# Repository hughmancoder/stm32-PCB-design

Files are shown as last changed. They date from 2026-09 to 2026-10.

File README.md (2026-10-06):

# stm32-PCB-design

PCB board for `STM32F103C8T6` Microcontroller, a micro usb power supply, a regulator to power the mcu to 3.3V, and a crystal oscillator for the mcu. It has a reset switch to boot the board, a UART interface UART (Universal Asynchronous Receiver-Transmitter) to  uses two wires to exchange serial data between devices without a shared clock, as well as Serial Wire Debug (SWD) which is a  hardware interface designed by ARM for programming and debugging ARM-based microcontrollers using a st-link programmer. 

## Schematic
**Microcontroller and USB**

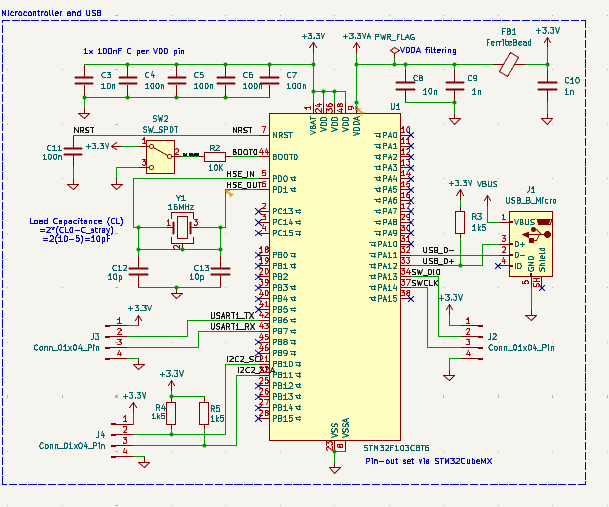
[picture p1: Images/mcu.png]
MCU


**Power Supply**

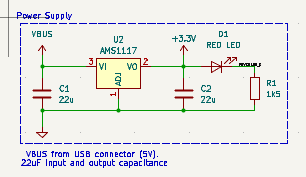
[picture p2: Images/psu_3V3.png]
Power Supply


## Board

**3D view**
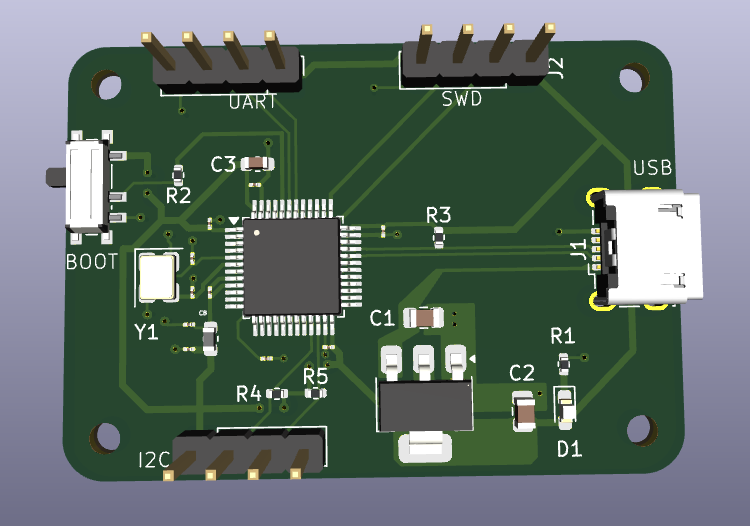
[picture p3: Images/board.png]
Board


**layout**
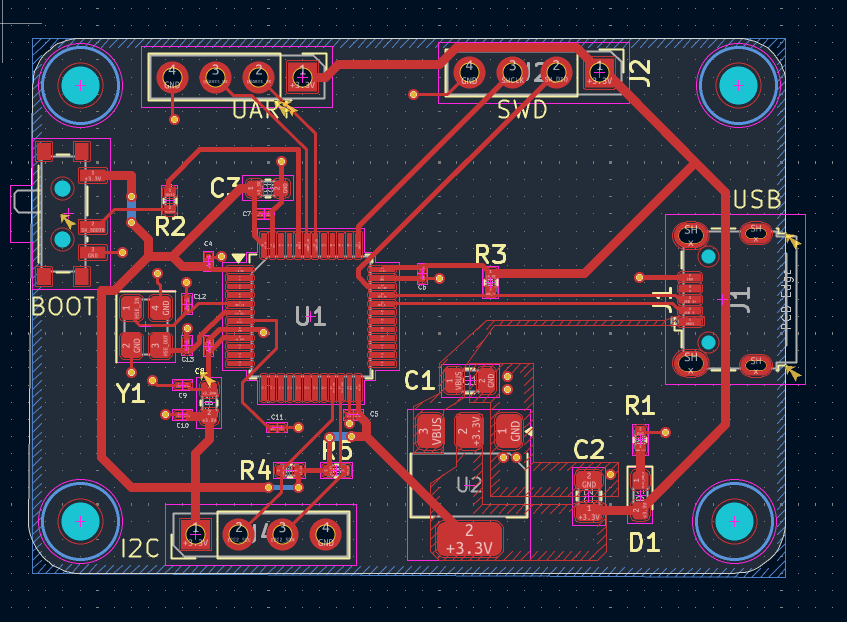
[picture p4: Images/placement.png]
Layout


## Manufacturing

Manufacturing gerber files, drill files, and Bill of Materials (BOM) are located in the `Manufacturing` folder.

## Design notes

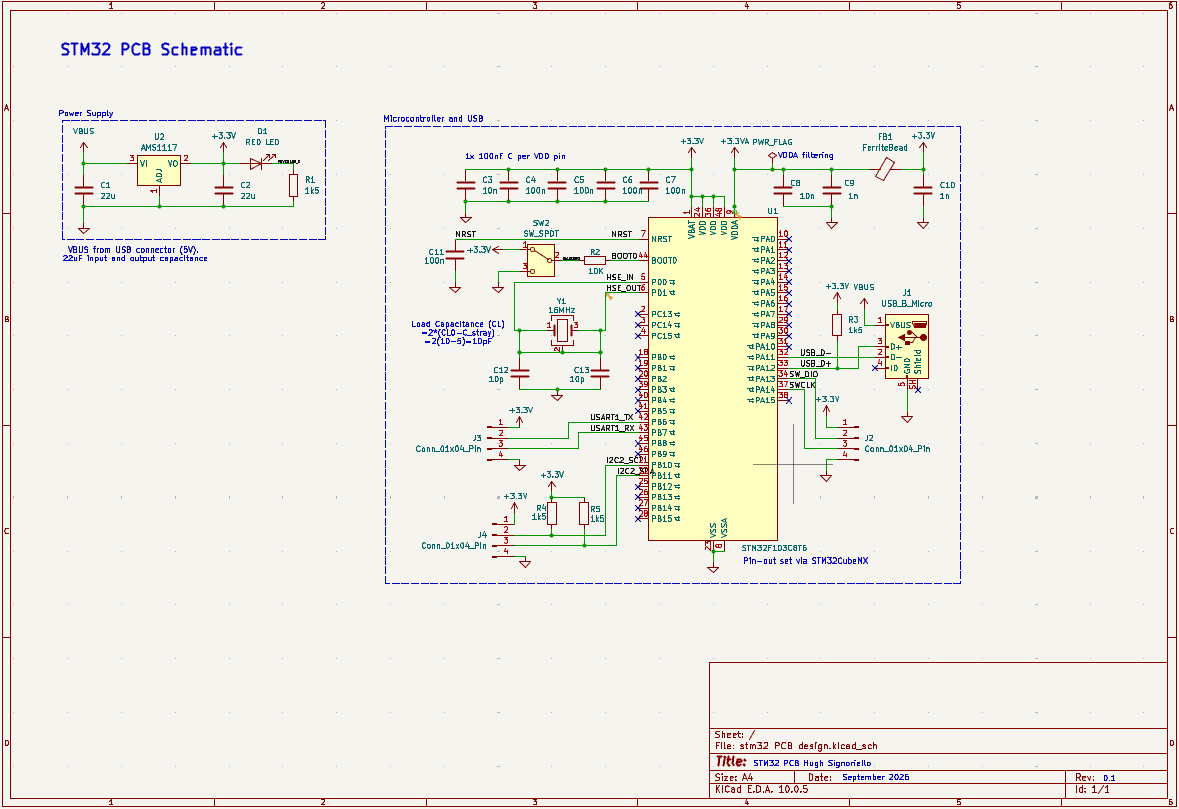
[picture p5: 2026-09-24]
Images/schematic_2026_09_24.png

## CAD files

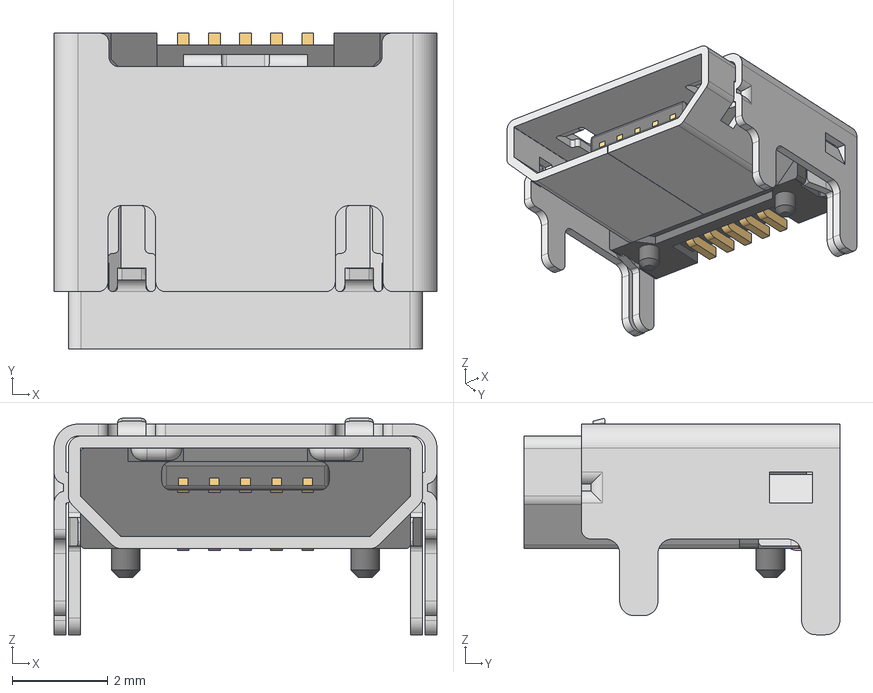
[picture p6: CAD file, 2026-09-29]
629105150521 (rev1).stp
8.00 x 6.60 x 4.52 mm
629105150521_Housing
629105150521_Pin1 x 4
629105150521_Pin2
629105150521_Shielding2
629105150521_Shielding

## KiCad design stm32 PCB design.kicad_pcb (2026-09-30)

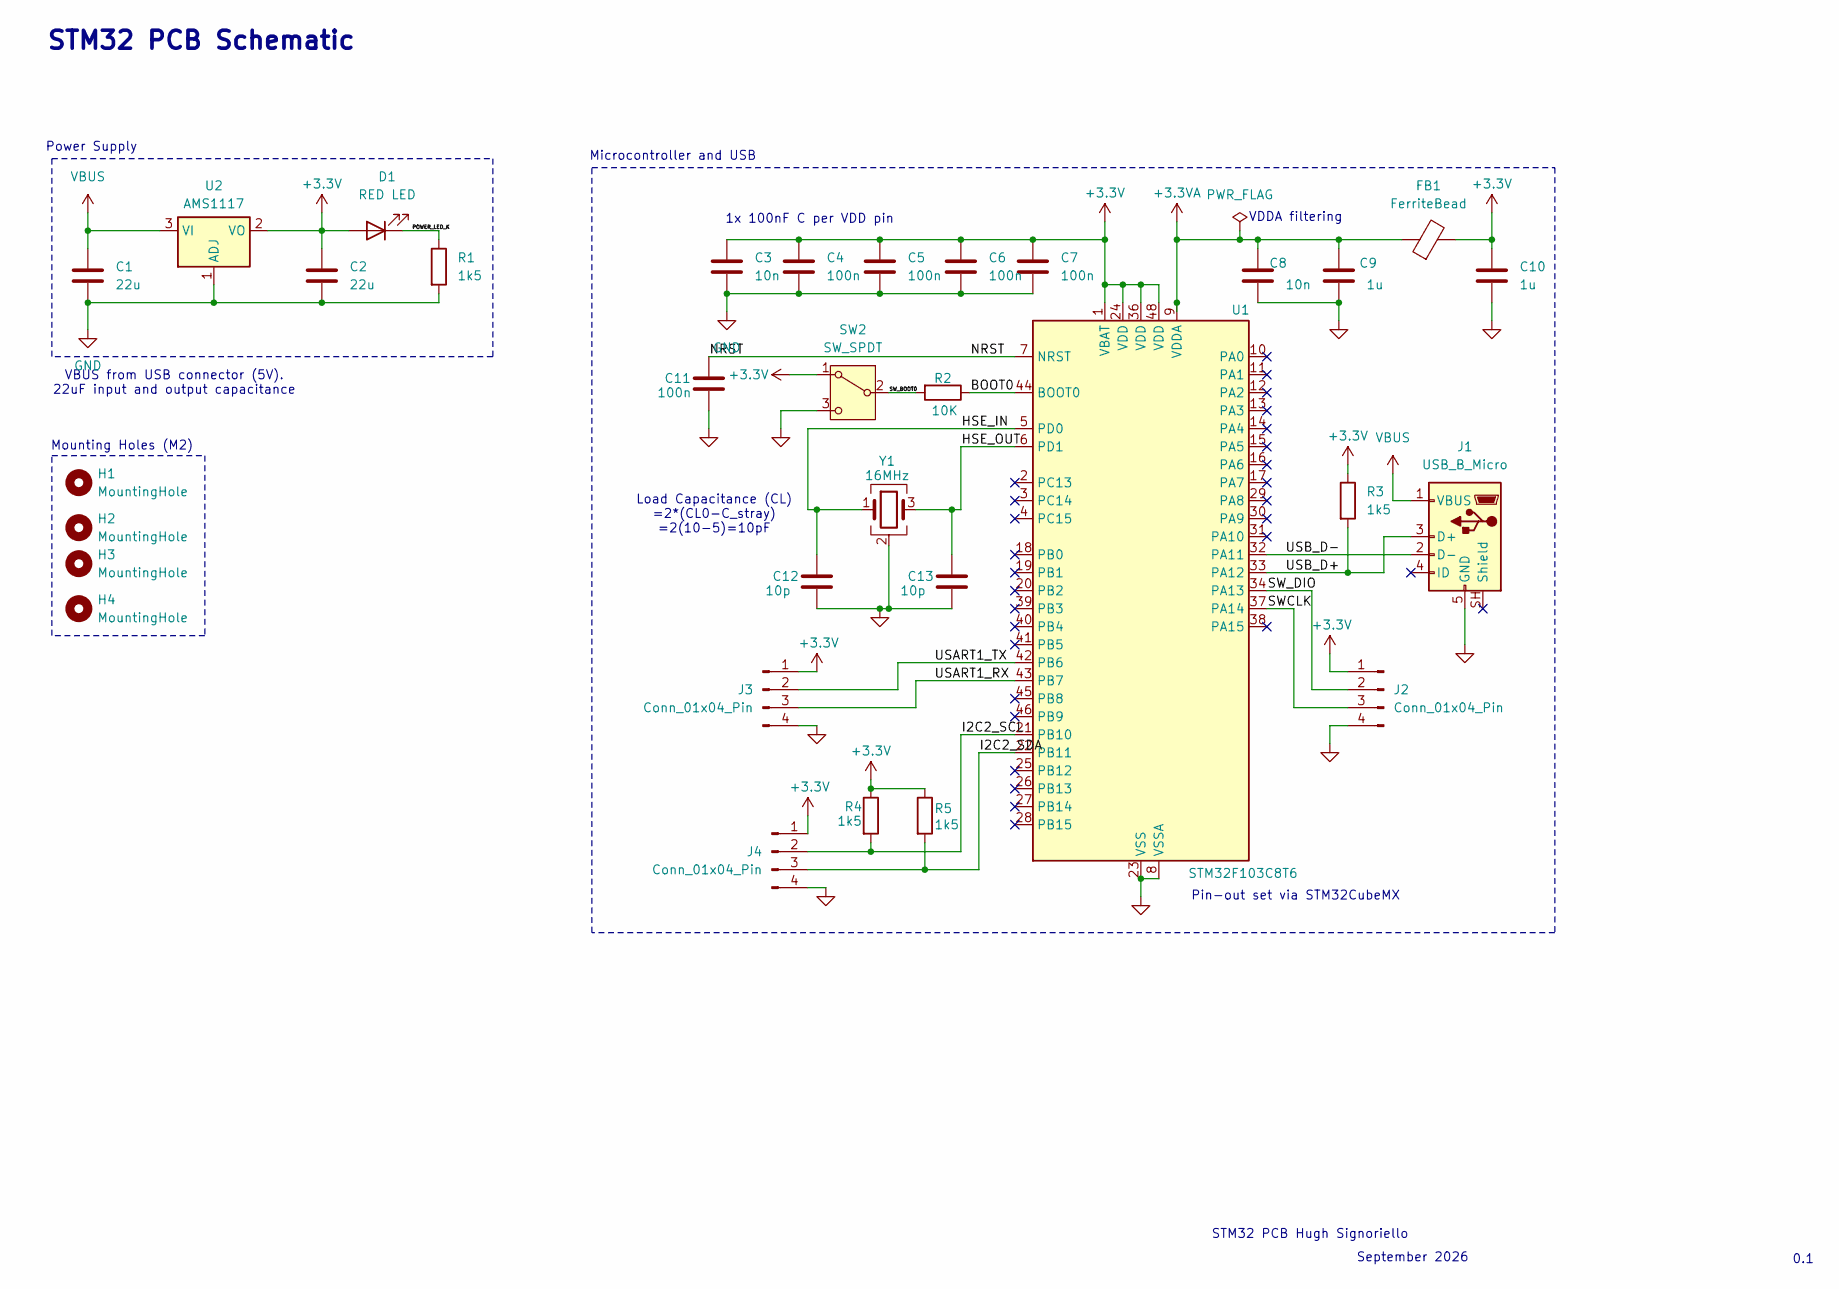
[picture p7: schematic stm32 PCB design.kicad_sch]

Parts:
C1, C2: 22u; C_0805_2012Metric
C3: 10n; C_0603_1608Metric
C4, C5, C6, C7, C11: 100n; C_01005_0402Metric
C8: 10n; C_01005_0402Metric
C9, C10: 1u; C_01005_0402Metric
C12, C13: 10p; C_01005_0402Metric
D1: RED LED; LED_0603_1608Metric_Pad1.05x0.95mm_HandSolder
FB1: FerriteBead; L_0603_1608Metric
H1, H2, H3, H4: MountingHole; MountingHole_2.2mm_M2
J1: USB_B_Micro; USB_Micro-B_Wuerth_629105150521
J2, J3, J4: Conn_01x04_Pin; PinHeader_1x04_P2.54mm_Vertical
R1, R3, R4, R5: 1k5; R_0402_1005Metric
R2: 10K; R_0402_1005Metric
SW2: SW_SPDT; SW_SPDT_PCM12
U1: STM32F103C8T6; LQFP-48_7x7mm_P0.5mm
U2: AMS1117; SOT-223-3_TabPin2
Y1: 16MHz; Crystal_SMD_3225-4Pin_3.2x2.5mm

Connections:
+3.3V: C2.1, C3.1, C4.1, C5.1, C6.1, C7.1, C10.1, D1.2 (A), FB1.2, J2.1, J3.1, J4.1, R3.1, R4.1, R5.1, SW2.1 (A), U1.1 (VBAT), U1.24 (VDD), U1.36 (VDD), U1.48 (VDD), U2.2 (VO)
+3.3VA: C8.1, C9.1, FB1.1, U1.9 (VDDA)
/BOOT0: R2.1, U1.44 (BOOT0)
/HSE_IN: C12.1, U1.5 (PD0), Y1.1
/HSE_OUT: C13.1, U1.6 (PD1), Y1.3
/I2C2_SCL: J4.2, R4.2, U1.21 (PB10)
/I2C2_SDA: J4.3, R5.2, U1.22 (PB11)
/NRST: C11.1, U1.7 (NRST)
/POWER_LED_K: D1.1 (K), R1.1
/SWCLK: J2.3, U1.37 (PA14)
/SW_BOOT0: R2.2, SW2.2 (B)
/SW_DIO: J2.2, U1.34 (PA13)
/USART1_RX: J3.3, U1.43 (PB7)
/USART1_TX: J3.2, U1.42 (PB6)
/USB_D+: J1.3 (D+), R3.2, U1.33 (PA12)
/USB_D-: J1.2 (D-), U1.32 (PA11)
GND: C1.2, C2.2, C3.2, C4.2, C5.2, C6.2, C7.2, C8.2, C9.2, C10.2, C11.2, C12.2, C13.2, J1.5 (GND), J2.4, J3.4, J4.4, R1.2, SW2.3 (C), U1.8 (VSSA), U1.23 (VSS), U1.35 (VSS), U1.47 (VSS), U2.1 (ADJ), Y1.2 (G), Y1.4 (G)
VBUS: C1.1, J1.1 (VBUS), U2.3 (VI)

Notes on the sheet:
VDDA filtering
VBUS from USB connector (5V). 22uF input and output capacitance
Power Supply
Microcontroller and USB
1x 100nF C per VDD pin
Pin-out set via STM32CubeMX
0.1
September 2026
STM32 PCB Hugh Signoriello
Load Capacitance (CL) =2*(CL0-C_stray) =2(10-5)=10pF
Mounting Holes (M2)
STM32 PCB Schematic

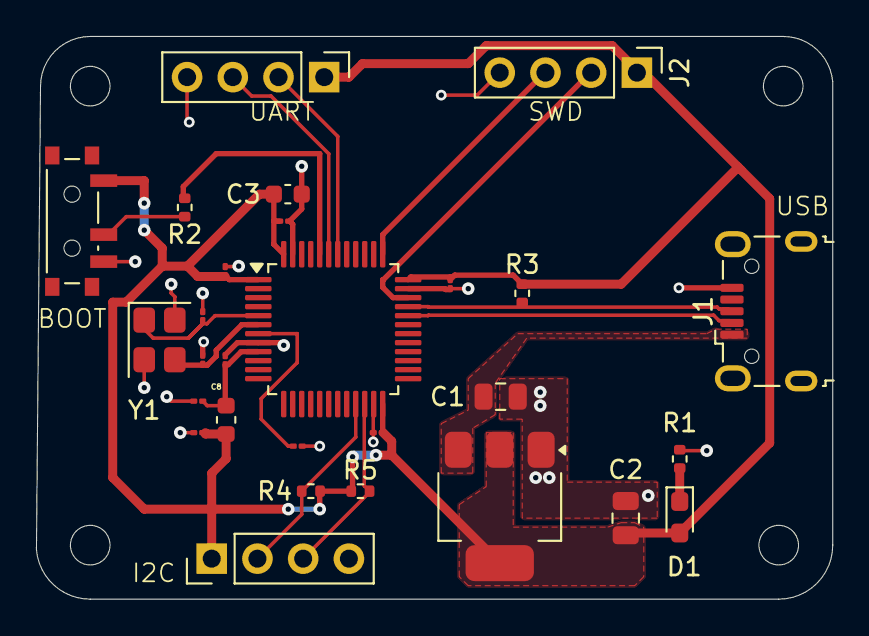
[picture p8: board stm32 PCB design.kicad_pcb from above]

Board: 2 copper layers, 44.2 x 31.3 mm, 32 parts (0 on the bottom side), 18 nets.

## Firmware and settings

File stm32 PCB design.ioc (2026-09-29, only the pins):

Mcu.UserName=STM32F103C8Tx
PA11.Signal=USB_DM
PA12.Signal=USB_DP
PA13.Signal=SYS_JTMS-SWDIO
PA14.Signal=SYS_JTCK-SWCLK
PB10.Signal=I2C2_SCL
PB11.Signal=I2C2_SDA
PB6.Signal=USART1_TX
PB7.Signal=USART1_RX
PD0-OSC_IN.Signal=RCC_OSC_IN
PD1-OSC_OUT.Signal=RCC_OSC_OUT

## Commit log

2026-09-22 setup STM32 PCB board configuration
    [.kicad_sch, stm32 PCB design.kicad_pcb, stm32 PCB design.kicad_sch]
2026-09-22 Untrack .history and local KiCad settings
2026-09-24 Schematic labelled and complete. EAD verified
    [stm32 PCB design.kicad_sch]
2026-09-29 Update PCB layout and add mounting holes
    [629105150521 (rev1).stp, stm32 PCB design.kicad_pcb, stm32 PCB design.kicad_sch]
2026-09-30 Documentation updated and design rule checks validated
    [stm32 PCB design-B_Cu.gbr, stm32 PCB design-B_Mask.gbr, stm32 PCB design-B_Paste.gbr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]
